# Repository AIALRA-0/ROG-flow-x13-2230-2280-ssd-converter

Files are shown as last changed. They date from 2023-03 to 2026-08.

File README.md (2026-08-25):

<div align="center">
  固态硬盘双板转接器结构图
  <p>以下硬件规格依据仓库设计资料与历史说明 [1], [2]</p>
  <h1>ROG Flow X13 2230 → 2280 SSD 双板转接器 <sup>[1], [2]</sup></h1>
  <p><strong>把机内 2230 M.2 接口延伸到全尺寸 2280 NVMe 固态硬盘 [1], [2]</strong></p>
  <p>硬件 v6 · 双板与双排线架构 · Altium 源文件 · 制造输出 · 三维封装 · 历史安装说明 [1], [2]</p>
  <p>
    
    
    
    
    
  </p>
  <p>
    <a href="#1-项目概览">项目概览</a> · <!-- [1], [2] -->
    <a href="#3-仓库内容">仓库内容</a> · <!-- [1], [2] -->
    <a href="#5-物料清单">物料清单</a> · <!-- [1], [2] -->
    <a href="#7-安装流程">安装流程</a> · <!-- [1], [2] -->
    <a href="README.en.md">English</a> <!-- [1], [2] -->
  </p>
</div>

> [!CAUTION]
> 这是需要拆机、断电、静电防护、焊接和机壳改造的硬件实验，操作失误可能损坏主板、固态硬盘、排线或外壳，也可能影响设备保修，仓库资料不能替代电气安全检查和制造商评审

## 1 项目概览

ROG Flow X13 的机内空间主要面向 2230 规格固态硬盘，本项目用两块电路板和两条柔性排线延伸 PCI Express 通道，让 2280 规格 NVMe 固态硬盘能够放置在机内另一位置 [1], [2]

发射端连接主机侧 2230 M.2 插槽，接收端承载 2280 固态硬盘

两块电路板通过 13 针和 20 针排线连接，这一角色划分依据工程命名、使用说明和实拍安装图综合确认 [1], [2]

<div align="center">

表 1.1 当前资料状态

| 项目 | 当前状态 | 阅读提示 |
| --- | --- | --- |
| 硬件工程 | v6 发射端与 v6 接收端 | 这是仓库中最新且完整的设计源文件 |
| 制造文件 | 两套 Gerber、钻孔和辅助报告 | 发射端 25 个文件，接收端 27 个文件 |
| 使用说明 | 标题仍标记 v4，正文还出现 v3 压缩包名 | 物料与安装经验可参考，版本名称不能当作 v6 变更说明 |
| 历史测试 | 2021 款 Flow X13 与一套 B550M 平台 | 性能和温度属于历史样机记录，未在当前提交重新测试 |
| 自动化检查 | 没有 GitHub Actions | 硬件源文件和制造文件需要人工复核 |
| 授权状态 | 仓库没有许可证文件 | 公开可见不代表自动获得复制、生产或再分发许可 |

</div>

<div align="center">
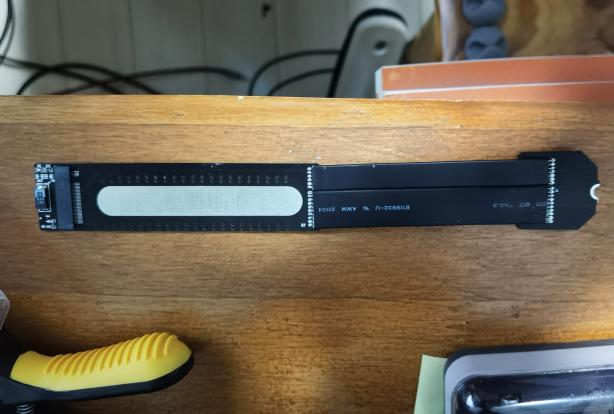
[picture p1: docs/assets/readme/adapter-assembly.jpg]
双板与柔性排线组成的转接器实拍
  
  <br>
  <sub>图 1.1 双板转接器与柔性排线实拍，图片来自仓库内历史使用说明 [1]</sub>
</div>

## 2 系统结构

<div align="center">

```mermaid
%% 信号与供电从主机侧向固态硬盘侧传递
flowchart TD
    A[ROG Flow X13<br>2230 M.2 主机接口] --> B[v6 发射端电路板]
    B --> C[13 针柔性排线]
    B --> D[20 针柔性排线]
    C --> E[v6 接收端电路板]
    D --> E
    E --> F[2280 NVMe 固态硬盘]
    E --> G[可选状态灯与断电保护]
    F --> H[导热垫与绝缘层]
    H --> I[机壳内规划位置]
```

图 2.1 双板转接器的连接关系

</div>

历史说明把两条排线写为 13 针和 20 针，文档标题同时写有“34pin”，两处计数并不一致 [1]

下单前应以 v6 原理图、焊盘编号和实物连接器逐项核对 [2]

## 3 仓库内容

<div align="center">

表 3.1 交付物导航

| 目录或文件 | 包含内容 | 适用场景 |
| --- | --- | --- |
| [`2230-2280转接板 屏蔽v6 发射端`](<2230-2280转接板 屏蔽v6 发射端>) | Altium 工程、原理图、PCB、封装库与 25 个制造输出 | 主机侧电路板编辑与生产 |
| [`2230-2280转接板 屏蔽v6 接收端`](<2230-2280转接板 屏蔽v6 接收端>) | Altium 工程、原理图、PCB、封装库、设计规则报告与 27 个制造输出 | 固态硬盘侧电路板编辑与生产 |
| [`3D封装`](3D封装) | 6 个 SolidWorks 零件文件 | 0201、0603、7343、SOT-23、NGFF 连接器等机械参考 |
| [`幻13 固态转接板 使用说明.docx`](<幻13 固态转接板 使用说明.docx>) | 物料、历史测试、打样、焊接和安装记录 | 理解设计意图与样机经验 |
| [`docs/readme-audit.md`](docs/readme-audit.md) | 资料来源、隐私清理和验证边界 | 审核本次首页升级 |
| [`docs/legacy/README.original.md`](docs/legacy/README.original.md) | 升级前的原始首页 | 追溯原始描述 |

</div>

制造压缩包与展开目录同时保留，压缩包便于下载，展开目录便于在线查看和差异审查

## 4 打样参数

<div align="center">

表 4.1 历史说明中的电路板参数

| 参数 | 发射端 | 接收端 | 备注 |
| --- | --- | --- | --- |
| 层数 | 2 层 | 2 层 | 依据历史说明 [1] |
| 建议板厚 | 0.8 mm | 0.6 mm 或 0.8 mm | 仓库样机记录为两端均使用 0.8 mm |
| 表面处理 | 沉金优先 | 沉金优先 | 历史样机使用喷锡，说明更推荐沉金 |
| 板框范围 | 文档写为 `10 × 10` 范围内 | 文档写为 `10 × 10` 范围内 | 原文没有写单位，下单前必须从 Gerber 复核 |
| 输出内容 | Gerber、钻孔、规则、测试点等 | Gerber、钻孔、DRC、规则、测试点等 | 两套输出生成于 2022 年 |

</div>

> [!IMPORTANT]
> 仓库没有提供当前制造商的阻抗、叠层、公差、铜厚、阻焊桥、最小孔径和柔性排线额定参数，PCI Express 属于高速差分接口，正式生产前应让板厂和具备高速设计经验的工程师完成可制造性与信号完整性复核

## 5 物料清单

<div align="center">

表 5.1 必装物料

| 位号类别 | 规格 | 数量 | 说明 |
| --- | --- | ---: | --- |
| 去耦电容 | 0201，220 nF | 8 | 按历史说明列出的必装数量 |
| M.2 连接器 | LOTES NGFF 67 针，2.3H，M-Key 4+5 | 1 | 接收端承载 2280 固态硬盘 |
| 柔性排线 | ADT 13 针，8 cm | 1 | 双板连接之一 |
| 柔性排线 | ADT 20 针，8 cm | 1 | 双板连接之一 |

</div>

<div align="center">

表 5.2 可选保护与指示物料

| 物料 | 规格 | 数量 | 使用条件 |
| --- | --- | ---: | --- |
| 钽电容 | 7343，220 µF，约 1.8 mm 高 | 1 | 用于历史设计中的电源缓冲方案 |
| 电阻 | 0603，1 kΩ | 1 | 状态灯或保护网络配套 |
| 电阻 | 0603，4.7 kΩ | 1 | 状态灯或保护网络配套 |
| 发光二极管 | 0603，绿色 | 1 | 可选状态指示 |
| 晶体管 | AO3400，SOT-23 | 1 | 可选断电保护电路 |
| 绝缘与屏蔽材料 | 醋酸布胶带、屏蔽贴 | 按需 | 建议采用绝缘层、屏蔽层、绝缘层的叠放方式 |

</div>

物料名称来自历史说明，实际位号、极性、耐压、额定电流和封装方向必须回到 v6 原理图与 PCB 核对 [1], [2]

## 6 历史测试记录

<div align="center">

表 6.1 历史测试平台

| 平台 | 主要配置 | 接口上限 | 用途 |
| --- | --- | --- | --- |
| ROG Flow X13 2021 | Ryzen 9 5900HS、GeForce RTX 3050 Ti | PCIe 3.0 ×4 | 机内安装与系统盘测试 |
| B550M 台式平台 | Ryzen 3 3100、8 GB DDR4-3200、GT 610 2 GB | 支持 PCIe 4.0 ×4 固态硬盘 | 转接板外部验证 |

</div>

<div align="center">

表 6.2 文档记录的系统盘样本

| 固态硬盘 | 容量 | 规格 | 文档记录 |
| --- | ---: | --- | --- |
| Samsung PM981a | 256 GB | 2280，PCIe 3.0 ×4 | 已作为系统盘测试 |
| Kioxia XG7 | 512 GB | 2280，PCIe 4.0 ×4 | 已作为系统盘测试 |
| Samsung PM9A1 | 2 TB | 2280，PCIe 4.0 ×4，标称 2.8 A | 已作为系统盘测试 |
| Western Digital SN530 | 1 TB | 2230，PCIe 3.0 ×4 | Flow X13 原装盘对照 |

</div>

历史说明声称，受测试平台限制未完成 PCIe 4.0 性能验证 [1]

文档给出的性能关系为 $P_{转接} / P_{直装} = 90\%$，持续读写温度约为 $50\text{–}70\,^{\circ}\mathrm{C}$，导热垫温差记录的计算关系为 $\Delta T = T_{加装前} - T_{加装后} = 10\,^{\circ}\mathrm{C}$ [1]

这些数值属于旧样机与旧软件环境的记录

仓库没有原始基准测试数据、测试脚本、重复次数和误差范围，因此不能据此保证其他固态硬盘、排线长度、板厂批次或环境温度下的结果 [1]

## 7 安装流程

- 第一步，备份数据，关闭系统并断开充电器，在防静电工作区拆开后盖

- 第二步，释放人体静电并可靠接地，再断开电池连接器，避免金属工具触碰主板裸露触点

- 第三步，在机外连接发射端、接收端、两条排线和待测固态硬盘，确认排线方向、焊点和 VCC 对 GND 没有短路

- 第四步，完成最小化上电识别与读写测试，确认稳定后再规划机内走线，历史说明推荐 8 cm 排线并在两端各预留约 0.5 cm 剥离长度 [1]

- 第五步，为主板与转接板增加耐热绝缘层，避开 HDMI 接口附近的裸露器件，并用导热垫填充固态硬盘与后盖之间的合理间隙

- 第六步，确认后盖不会持续压迫排线、连接器或元件，再装回外壳并复测识别、温度、休眠唤醒和持续读写

<div align="center">
  <table>
    <tr>
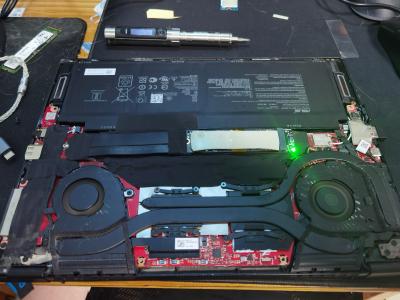
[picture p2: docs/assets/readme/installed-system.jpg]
转接板安装在 ROG Flow X13 内部
      <td align="center"></td>
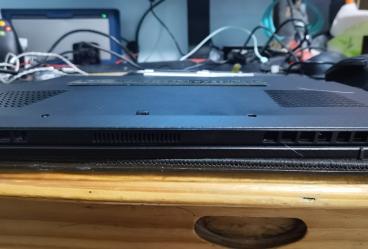
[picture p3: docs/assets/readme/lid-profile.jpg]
安装后的后盖侧面轮廓
      <td align="center"></td>
    </tr>
    <tr>
      <td align="center"><sub>机内安装位置</sub></td>
      <td align="center"><sub>历史样机后盖轮廓</sub></td>
    </tr>
  </table>
  <sub>图 7.1 历史样机安装状态，图片来自使用说明 [1]</sub>
</div>

> [!WARNING]
> 历史说明要求切除外壳内的部分塑料凸起，并指出中间螺钉可能无法继续安装，实拍还显示后盖存在轻微隆起，这些改造会改变机械受力、跌落防护和保修条件，应在操作前自行评估并准备可恢复方案

2022 款机型的无线网卡区域结构可能不同，历史说明认为排线可能需要更短 [1]

仓库没有给出针对不同年份机型的尺寸图，不应把 2021 款样机布局直接套用于其他版本

## 8 焊接规范

历史说明建议使用低温或中温焊锡、小号马蹄头或尖头烙铁、RELIFE-422 助焊剂，并在完成后重点检查密脚连接器、虚焊和 VCC 对 GND 短路 [1]

原文把推荐焊接温度写成 `300s`，这个字符串可能是单位误写，也可能是其他记录错误 [1]

仓库没有足够证据把它改成 $300\,^{\circ}\mathrm{C}$，请依据焊锡、连接器和 PCB 工艺规范重新确定温度曲线

屏蔽材料的历史叠放顺序为醋酸布绝缘层、屏蔽贴、醋酸布绝缘层，任何导电屏蔽材料都不能直接接触焊点、连接器或主板器件

## 9 验证状态

<div align="center">

表 9.1 可验证证据

| 检查项 | 仓库证据 | 当前结论 |
| --- | --- | --- |
| 接收端设计规则检查 | 2022 年 6 月 9 日 DRC 报告 [3] | 0 项规则违规，1 项未镀层多层焊盘警告，位置为 CN2-59 的 GND 焊盘 |
| 发射端制造输出 | 2022 年 8 月 8 日 Gerber 与测试点输出 [4] | 25 个输出文件齐备，仓库没有同批次 DRC 报告 |
| 接收端制造输出 | 2022 年 6 月 9 日 Gerber、钻孔、DRC 与测试点输出 [5] | 27 个输出文件齐备 |
| 使用说明结构 | 97 个段落、11 个图片关系 | 已清理作者字段、修订会话和两个个人联系方式 |
| 文档视觉复核 | 当前环境缺少 LibreOffice | 只完成结构化回退检查，未完成逐页渲染验收 |
| 自动化硬件测试 | 没有 CI、网表对比或制造重生成脚本 | 修改设计后必须在 Altium 中重新生成全部输出 |

</div>

接收端 DRC 的 0 项规则违规只代表当时规则集没有报告违规，1 项警告仍需人工确认 [3]

历史报告不能替代对当前制造文件的重新检查

## 10 版本状态

<div align="center">

表 10.1 版本线索

| 位置 | 版本线索 | 处理方式 |
| --- | --- | --- |
| 发射端与接收端工程目录 | v6 | 作为当前硬件基线 |
| 制造输出 | 文件名标记 v6 | 与当前工程配套保留 |
| Word 使用说明标题 | v4 | 作为历史安装说明，不声称覆盖 v6 全部改动 |
| Word 使用说明正文 | 出现 v3 制造压缩包名称 | 标记为过期下单说明，不删除原始上下文 |
| 排线计数 | 13 针加 20 针，与标题中的 34pin 不一致 | 要求下单前逐针核对 |

</div>

仓库没有原理图变更日志、v4 到 v6 的差异说明、板厂订单参数、固件、软件驱动或可复现实验数据

## 11 隐私防护

公开附件已完成定点脱敏

清理范围包括 Word 作者与最后修改者字段、修订会话标识、个人联系方式、制造报告中的临时目录，以及 Altium 项目和设计文件中的确定性工作站路径前缀

两套制造压缩包由对应展开目录重新生成，既同步了脱敏结果，也修复了旧压缩包中的中文文件名乱码

重新封装后的文件与各自展开目录逐项一致 [4], [5]

设备标签、条码和可能包含唯一标识的照片没有用于 README 首页

历史文档仍包含部分设备照片，公开再分发前应根据自己的风险标准复核图片内容

## 12 参考资料

[1] AIALRA, “幻13 固态转接板 使用说明,” Word document, Mar. 2023. [Online]. Available: [`幻13 固态转接板 使用说明.docx`](<幻13 固态转接板 使用说明.docx>)

[2] AIALRA, “ROG Flow X13 2230–2280 SSD converter, v6 Altium sources,” 2022. [Online]. Available: [`发射端工程`](<2230-2280转接板 屏蔽v6 发射端>) and [`接收端工程`](<2230-2280转接板 屏蔽v6 接收端>)

[3] AIALRA, “Design Rule Check — 接收端 V6,” Jun. 9, 2022. [Online]. Available: [`Design Rule Check - 接收端V6.drc`](<2230-2280转接板 屏蔽v6 接收端/Project Outputs for 2230-2280转接板 屏蔽v6 接收端/Design Rule Check - 接收端V6.drc>)

[4] AIALRA, “Project Outputs for 2230–2280 转接板 屏蔽 v6 发射端,” Aug. 8, 2022. [Online]. Available: [`发射端制造输出`](<2230-2280转接板 屏蔽v6 发射端/Project Outputs for 2230-2280转接板 屏蔽v6 发射端>)

[5] AIALRA, “Project Outputs for 2230–2280 转接板 屏蔽 v6 接收端,” Jun. 9, 2022. [Online]. Available: [`接收端制造输出`](<2230-2280转接板 屏蔽v6 接收端/Project Outputs for 2230-2280转接板 屏蔽v6 接收端>)

<div align="center">
  <a href="README.en.md"><strong>English documentation</strong></a>
  <br>
  <sub>仓库没有明确许可证，使用前请复核电气、机械、散热和法律约束</sub>
</div>

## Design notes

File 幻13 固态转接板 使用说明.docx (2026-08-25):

m.2-2230-34pin-fpc转接板v4 使用说明

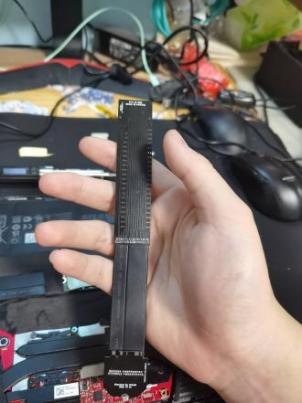
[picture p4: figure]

*本产品为DIY产品，如操作不当造成的产品损坏本人概不负责！！！

*本产品为DIY产品，如操作不当造成的产品损坏本人概不负责！！！

*本产品为DIY产品，如操作不当造成的产品损坏本人概不负责！！！

安装教学：（b站） (https://www.bilibili.com/video/BV1ZZ4y1b7DJ)

本教程比较长，请仔细看完，阅读每一个提示，不要觉得麻烦，本教程旨在尽可能减小你翻车概率！

本教程不需要任何理论基础，只需要你认真阅读提示步骤，不要嫌麻烦，有一颗勇敢尝试的心！

1.本人测试条件为

测试机1：rog 幻13 2021 3050ti 5900hs 固态支持pcie3.0x4

测试机2：影驰B550M幻影 gt610冰铠士2G R3-3100 海盗船8GB-DDR4-3200 固态支持pcie4.0x4

以下固态均作为系统盘测试：

测试固态1：pm981a-00000 256GB 2280 pcie3.0x4

测试固态2：恺侠 XG7 512GB 2280 pcie4.0x4

测试固态3：pm9a1-00B00-7401Q 2TB 2280 2.8A标准版 pcie4.0x4

测试固态4：sn530-幻13原装 1TB 2230 pcie3.0x4

测试转接板参数：

pcb：0.8mm板厚（发射端/接收端） 镀锡 手工焊接

带状态指示灯和断电保护电路（指示灯如图，可选，会增加一点点耗电量）


排线：ADT 13pin排线 8cm*1

ADT 20pin排线 8cm*1

物料（超链接仅供选料参考）：

以下为转接电路，必要

0201 电容 220nf *8： (https://detail.tmall.com/item.htm?id=662752557232&spm=a1z09.2.0.0.707d2e8dlbeid3&_u=c349oaln0b49)

LOTES连接器 NGFF 67pin 2.3H M-Key 4+5 *1 (https://item.taobao.com/item.htm?spm=a1z09.2.0.0.707d2e8dlbeid3&id=562398166085&_u=c349oaln72b0)

ADT 13pin排线 8cm*1 (https://item.taobao.com/item.htm?spm=a1z09.2.0.0.707d2e8dlbeid3&id=590612347734&_u=c349oaln3e1f)

ADT 20pin排线 8cm*1 (https://item.taobao.com/item.htm?spm=a1z09.2.0.0.707d2e8dlbeid3&id=590612347734&_u=c349oaln3e1f)

以下为保护和指示灯电路，可选

7343 220uF 钽电容 1.8mm*1 (https://detail.tmall.com/item.htm?id=600745526550&spm=a1z09.2.0.0.707d2e8dlbeid3&_u=c349oalnfa9c)

0603 1kohm 电阻*1 (https://item.taobao.com/item.htm?spm=a1z09.2.0.0.707d2e8dlbeid3&id=617906881004&_u=c349oaln7a2d)

0603 4.7kohm 电阻*1 (https://detail.tmall.com/item.htm?id=529532295464&spm=a1z09.2.0.0.707d2e8dlbeid3&_u=c349oalnb110)

0603 led 绿*1 (https://detail.tmall.com/item.htm?id=626135116246&spm=a1z09.2.0.0.707d2e8dlbeid3&_u=c349oalnd78c)

Ao3400 三极管 sot-23 *1 (https://detail.tmall.com/item.htm?id=540855145307&spm=a1z09.2.0.0.707d2e8dlbeid3&_u=c349oaln11ba)

屏蔽措施

醋酸布胶带 (https://item.taobao.com/item.htm?spm=a1z09.2.0.0.3ab22e8deFqG9W&id=621074030810&_u=c349oaln03f4)

屏蔽胶带 (https://detail.tmall.com/item.htm?id=636662706214&spm=a1z09.2.0.0.3ab22e8deFqG9W&_u=c349oaln5084)

2. 测试结果

-目前pcie4.0因为测试平台原因没有成绩，大家就先按3.0的标规跑，pcie4.0向下兼容3.0

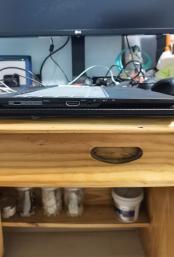
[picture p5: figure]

-合盖后稍微一点点突起，不影响正常放置和翻转

-几块测试硬盘都在安装正确且良好的情况下转接跑到了直接安装90%左右的测试性能（各项都是）

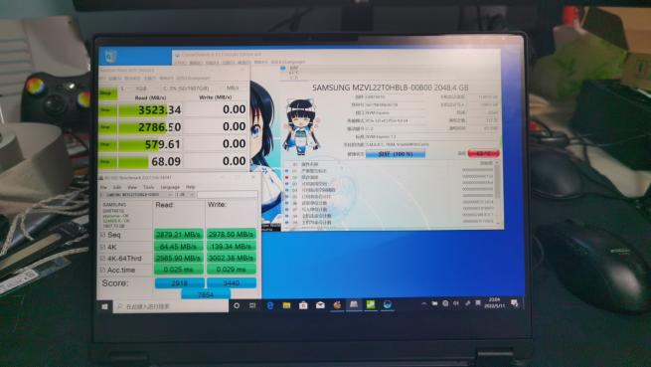
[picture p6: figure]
1be5a2afa95e1cfc

-跑持续读写没有过度发热的情况，基本都是50起步，60稳定，最高70附近徘徊（上图未加散热贴，加了就不会过红了>=70°C）

-以往版本测试成绩请看B站aialra动态和视频

幻13 2230固态硬盘位改装2tb pm9a1 （v4-最终版本） (https://www.bilibili.com/video/BV1ZZ4y1b7DJ)

幻13 固态硬盘 2230转接2280 解决方案（V3） (https://www.bilibili.com/video/BV1r44y1V74M?spm_id_from=333.999.0.0)

ROG 幻13 加装三星 pm981a 2280长度固态硬盘（V2） (https://www.bilibili.com/video/BV1xZ4y1m7rL?spm_id_from=333.999.0.0)

ROG 幻13转接2280固态：（V1）BV1Kb4y1t7UK (https://www.bilibili.com/video/BV1Kb4y1t7UK?spm_id_from=333.999.0.0)

3.安装注意事项

-幻13电池接口慎拔！断电之前请释放静电，保持人体接地且在网上查阅了华硕电池拆装教程

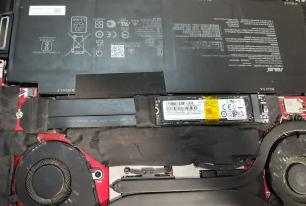
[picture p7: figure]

-因为幻13主板上突起物较多，推荐排线距离为8cm，其他长度也是可以的，根据自己需要进行裁剪即可，两端预留0.5cm剥线就行，22款的幻13因为后面有可更换的网卡母座，所以距离可能需要短一些

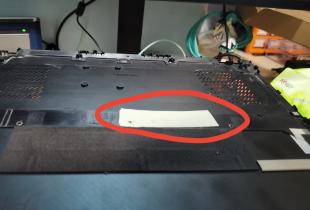
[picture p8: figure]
IMG_20220512_211428_edit_138424334945543
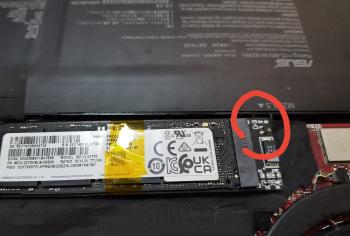
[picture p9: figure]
IMG_20220512_212329_edit_139205611571986

-幻13外壳需要剪掉固态位置上方的几块塑料突起，否则难以合盖，中间的螺丝在本版本下是拧不上的，建议对电池螺丝部分也进行一定修剪，如果担心失去保修，可以去咸鱼或者淘宝搜索幻13外壳配件作为替代产品

-幻13 主板需要做好绝缘，耐热与防静电措施，建议拿醋酸布胶带贴满敏感区域，目前测试来看不会影响散热性能（图为参考粘贴位置）

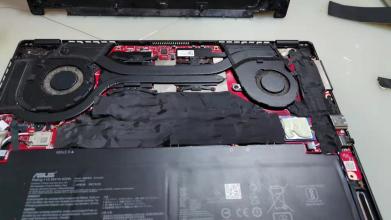
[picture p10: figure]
醋酸布粘贴位置参考

-小心固态安装位后hdmi接口的部分的裸露器件，如果操作不当容易造成击穿

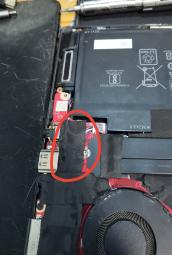
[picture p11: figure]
IMG_20220512_211524_edit_138471394742931

-尽量用导热胶/散热贴填充固态与外壳缝隙，提高散热性能，在有导热胶的情况下温度能下降10°C左右

-装机前请务必在固态硬盘盒/测试机上测试确保能用！！！

4.pcb打样教程

网上搜，pcb如何打样（推荐嘉立创），然后把压缩包里的两个压缩文件（一共是两块pcb，两个订单）发给板厂即可，参数照下面调就行，两块pcb都在10x10范围内

压缩包文件：m.2-2230-34pin-fpc转接板 发射端 v3.zip 以及 m.2-2230-34pin-fpc转接板 接收端 v3.zip

5.pcb须知：

推荐厚度：0.8mm（发射端）/0.6或0.8mm（接收端）

推荐颜色：随个人喜好

推荐焊接方式：无技术基础情况下请走SMT，有密集引脚焊接技术保证的可自行焊接

层数：2

镀层：镀金>镀锡

6. 屏蔽须知

推荐在转接板排线连接处铺上屏蔽胶带以及绝缘胶带

推荐电脑主板上铺满醋酸布胶带，对电源部分贴屏蔽胶带 推荐屏蔽胶带结构：

醋酸布

屏蔽贴纸

醋酸布

10.焊接须知

板厂代工：焊接步骤可直接联系板厂代工，具体请自己联系板厂，额外收费

自己焊接：

推荐温度：300s

推荐焊锡：低温/中温

烙铁头：推荐小马蹄头/尖头

推荐助焊剂（重要）：别贪便宜，我用的relife-422

焊接教程：b站自己搜

提示：焊接后请使用万用表确保没有短路，虚焊，一定要确保vcc和gnd没有短路

其他

如有问题请联系QQ：[REDACTED]

拼团，资料下载请加群：QQ：[REDACTED

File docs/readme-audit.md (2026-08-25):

# README 资料审计记录

## 1 审计范围

本记录对应 `ROG-flow-x13-2230-2280-ssd-converter` 仓库首页重建，审计覆盖 README、Altium 设计源文件、制造输出、压缩包、三维封装和 Word 使用说明

## 2 事实来源

<div align="center">

表 2.1 资料来源与用途

| 来源 | 用途 | 可信边界 |
| --- | --- | --- |
| 发射端与接收端 Altium 工程 | 确认 v6 工程结构、双板组成和制造文件 | 未在本环境重新打开 Altium 工程 |
| 接收端设计规则报告 | 确认历史检查记录为 0 项规则违规、1 项未镀层多层焊盘警告 | 报告生成于 2022 年 6 月 9 日 |
| 两套制造输出 | 确认 Gerber、钻孔、光圈、规则和测试点报告齐备 | 未重新下单生产，也未执行制造商可制造性审查 |
| 《幻13 固态转接板 使用说明》 | 整理物料、测试平台、安装步骤、温度与性能记录 | 文档标题仍写 v4，正文还出现 v3 压缩包名称，与仓库 v6 工程不同步 |
| 文档内 11 张实拍图 | 选择转接板、安装状态和后盖轮廓展示图 | 含设备标签的照片未用于 README 首页 |

</div>

## 3 信息修正

<div align="center">

表 3.1 发现的问题与处理结果

| 问题 | 处理结果 |
| --- | --- |
| 原 README 只有标题和一句描述 | 重建为中文优先、英文备份的图文首页 |
| 使用说明标题为 v4，正文出现 v3 压缩包，工程为 v6 | 保留全部资料，并在首页显式标注版本差异 |
| 使用说明出现两个个人联系方式 | 定点遮盖，同时清除文档作者和修订会话元数据 |
| 制造报告与工程文件含历史工作站绝对路径 | 文本报告、项目配置、设计二进制文件中的确定性路径前缀完成脱敏 |
| 两个制造压缩包含旧路径和乱码中文文件名 | 由对应输出目录重新封装，分别保留 25 个与 27 个文件 |
| 文档写有 `300s` 焊接温度 | 按原文保留为歧义，不擅自改写为摄氏温度 |

</div>

## 4 验证边界

当前环境缺少 LibreOffice，因此无法完成 Word 文档逐页渲染复核，已改用压缩结构、段落数量、图片关系、敏感字符串和核心属性检查

Altium 与 SolidWorks 桌面软件未在当前环境中启用，因此源文件验证限于文件头、结构清单、确定性路径替换和配套制造输出一致性检查

## 5 原始首页

升级前的完整首页保存在 [`docs/legacy/README.original.md`](legacy/README.original.md)，便于追溯且不会丢失原始描述

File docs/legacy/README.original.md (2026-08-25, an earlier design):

# ROG-flow-x13-2230-2280-ssd-converter

幻13 2230-2280固态转接板

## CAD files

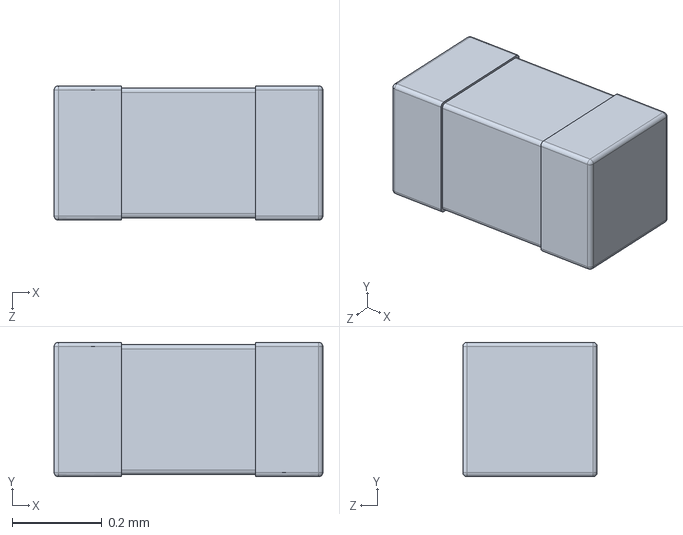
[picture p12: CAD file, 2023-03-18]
3D封装/0201电容.sldprt
0.6 x 0.3 x 0.3 mm

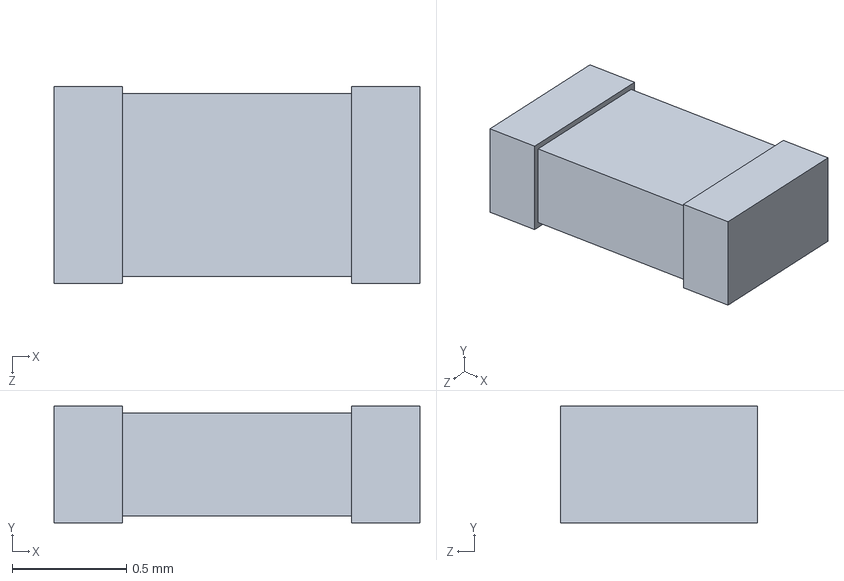
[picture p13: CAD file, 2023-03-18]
3D封装/0603电阻.sldprt
1.60 x 0.51 x 0.86 mm

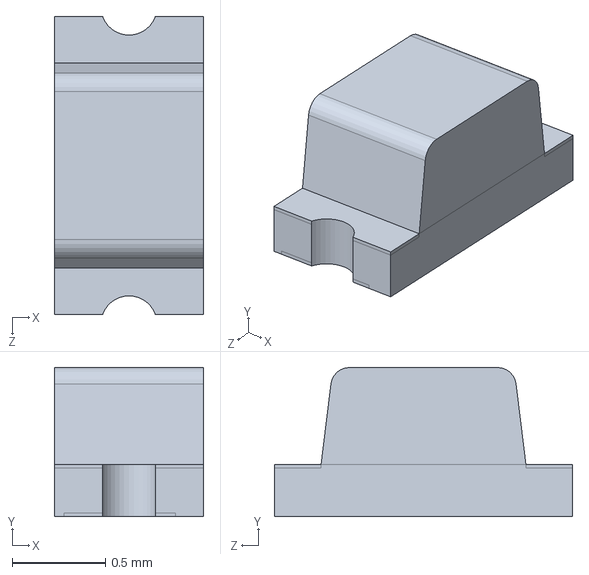
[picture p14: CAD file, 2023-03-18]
3D封装/0603 绿 led.sldprt
0.8 x 0.8 x 1.60 mm

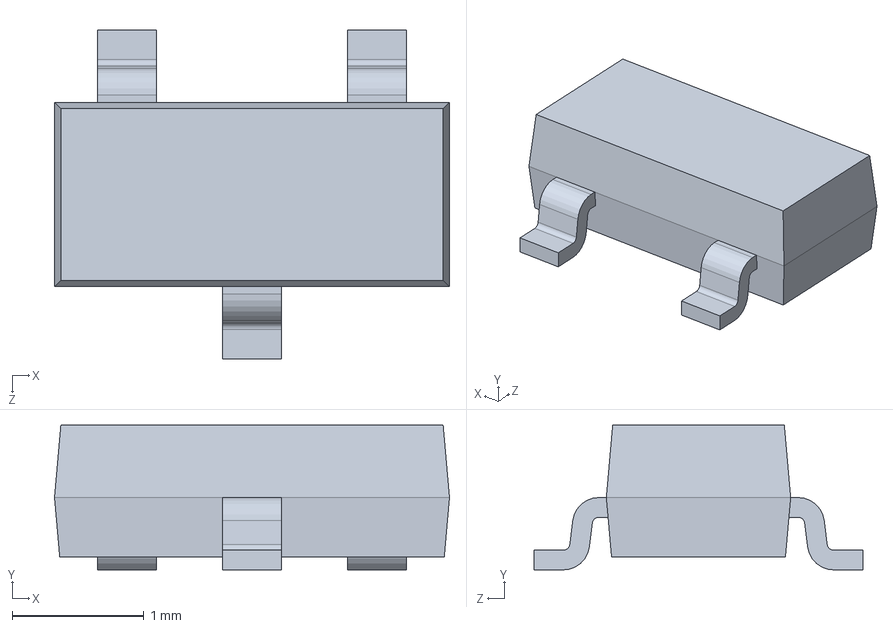
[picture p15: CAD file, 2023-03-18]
3D封装/SOT23三极管.sldprt
3.00 x 1.10 x 2.50 mm

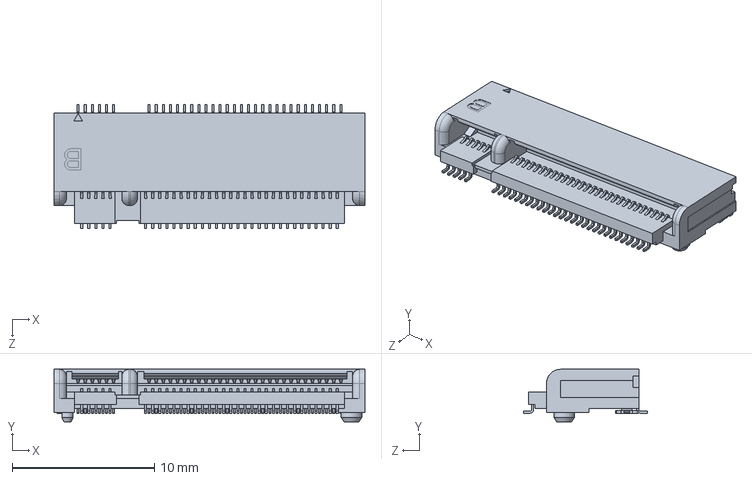
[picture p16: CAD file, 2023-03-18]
3D封装/NGFF 3.2H.SLDPRT
21.9 x 3.70 x 8.70 mm

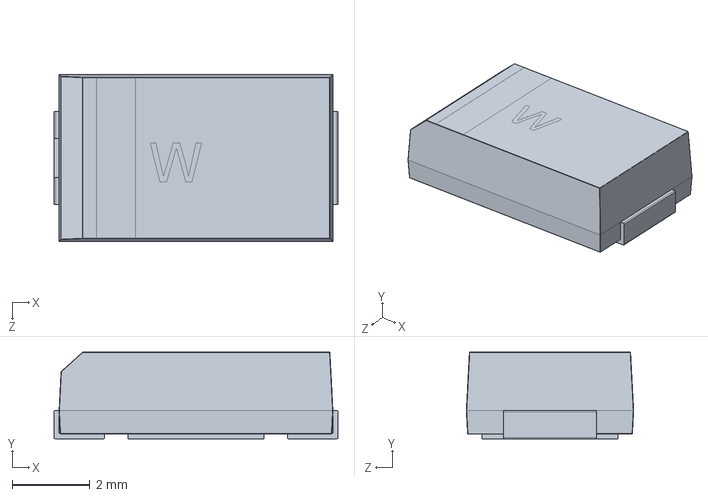
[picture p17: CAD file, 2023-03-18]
3D封装/7343钽电容.sldprt
7.30 x 2.23 x 4.30 mm
